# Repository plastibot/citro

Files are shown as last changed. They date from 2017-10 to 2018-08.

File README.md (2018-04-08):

# citro

A 3D Printed Biped Robot based on MiniPlan6 integrating a Pi Zero W, Pi Camera, Speakers, Microphone and Accelerometer.

## Firmware Installation Instructions

### Install Arduino
Install Arduino IDE 1.6.8 level which can be found on previous relelases at the Arduino website [here](https://www.arduino.cc/en/Main/OldSoftwareReleases#1.5.x)

### install ESP8266 suite
Starting with 1.6.4, Arduino allows installation of third-party platform packages using Boards Manager. 

- Start Arduino and open Preferences window.
- Enter http://arduino.esp8266.com/stable/package_esp8266com_index.json into Additional Board Manager URLs field. You can add * - multiple URLs, separating them with commas.
- Open Boards Manager from Tools > Board menu and install esp8266 platform.
- Select your ESP8266 board from Tools > Board menu after installation.

### Download tool for SPIFFS support

- Download the tool: https://github.com/esp8266/arduino-esp8266fs-plugin/releases/download/0.3.0/ESP8266FS-0.3.0.zip.
- In your Arduino sketchbook directory, create tools directory if it doesn’t exist yet
- Unpack the tool into tools directory (the path will look like <home_dir>/Arduino/tools/ESP8266FS/tool/esp8266fs.jar)
- Restart Arduino IDE

``` bash
$ cd ~/Arduino
$ makedir tools
$ cd tools
$ wget https://github.com/esp8266/arduino-esp8266fs-plugin/releases/download/0.3.0/ESP8266FS-0.3.0.zip
$ unzip ESP8266FS-0.3.0.zip
```

### Downloading required Libraries
Download the following libraries from adafruit into your Arduino/libraries folder

``` bash
$ cd ~/Arduino/libraries
$ git clone https://github.com/adafruit/Adafruit_SSD1306.git
$ git clone https://github.com/adafruit/Adafruit-GFX-Library.git
$ git clone https://github.com/adafruit/Adafruit-PWM-Servo-Driver-Library.git

```

### Clone Repository for Citro

```
$ cd ~
$ git clone https://github.com/plastibot/citro.git
```

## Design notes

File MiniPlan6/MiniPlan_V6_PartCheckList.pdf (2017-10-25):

Part No. | Print Settings | Qty.

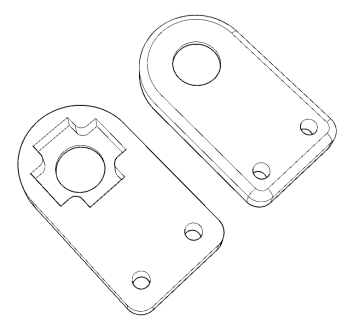
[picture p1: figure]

MiniPlan6_11 | Supports: No Resolution: 0.2mm Infill: 30% | □ 4

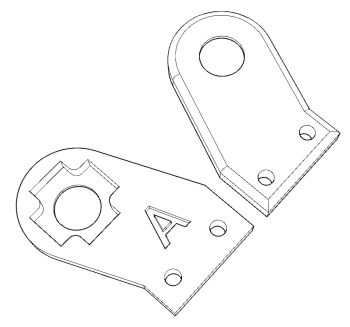
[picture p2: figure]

MiniPlan6_12A | Supports: No Resolution: 0.2mm Infill: 30% | □ 3

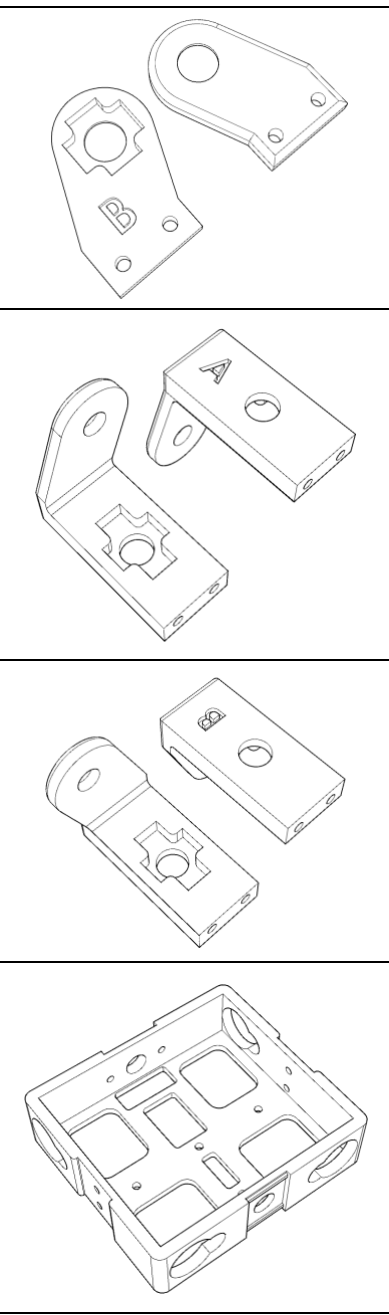
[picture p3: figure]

MiniPlan6_12B | Supports: No Resolution: 0.2mm Infill: 30% | □ 3
MiniPlan6_13A | Supports: No Resolution: 0.2mm Infill: 30% | □ 2
MiniPlan6_13B | Supports: No Resolution: 0.2mm Infill: 30% | □ 2
MiniPlan6_20 | Supports: No Resolution: 0.2mm Infill: 30% | □ 1

Part No. | Print Settings | Qty.

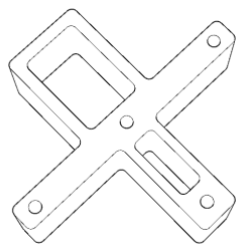
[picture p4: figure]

MiniPlan6_21 | Supports: No Resolution: 0.2mm Infill: 30% | □ 1
MiniPlan6_22B | Supports: No Resolution: 0.2mm Infill: 30% | □ 1

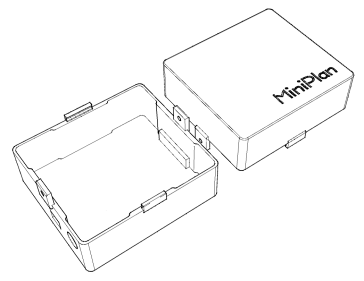
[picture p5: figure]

MiniPlan6_23B | Supports: No Resolution: 0.2mm Infill: 30% | □ 1

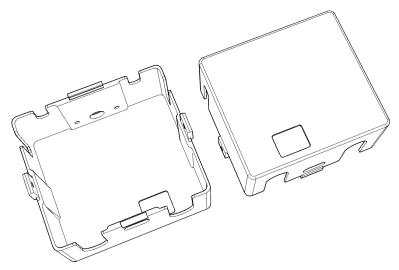
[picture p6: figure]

MiniPlan6_24B | Supports: No Resolution: 0.2mm Infill: 30% | □ 1

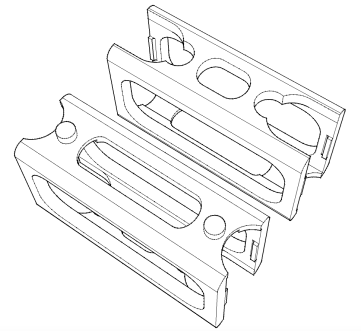
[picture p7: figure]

MiniPlan6_30 | Brim: Yes Supports: No Resolution: 0.2mm Infill: 30% | □ 2
MiniPlan6_31L | Supports: No Resolution: 0.2mm Infill: 20% | □ 1

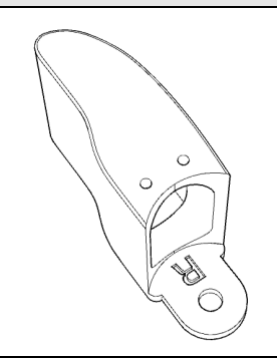
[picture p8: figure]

Part No. | Print Settings | Qty.
MiniPlan6_31R | Supports: No Resolution: 0.2mm Infill: 20% | □ 1

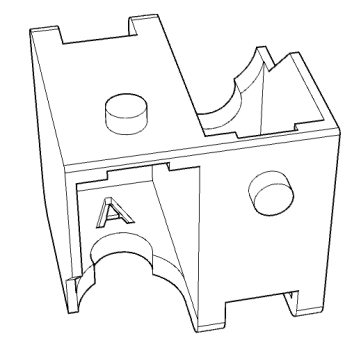
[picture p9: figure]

MiniPlan6_40A | Supports: Yes Resolution: 0.2mm Infill: 30% | □ 1

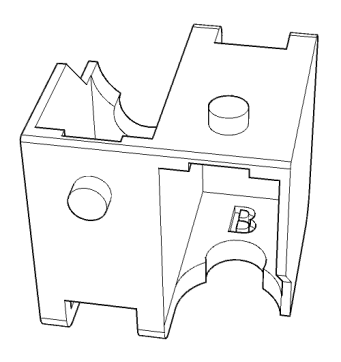
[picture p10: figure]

MiniPlan6_40B | Supports: Yes Resolution: 0.2mm Infill: 30% | □ 1

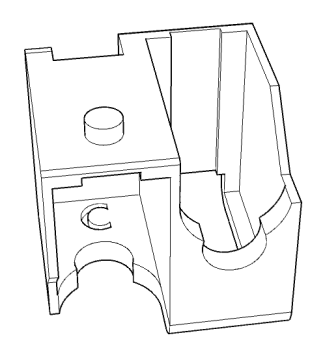
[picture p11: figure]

MiniPlan6_40C | Supports: Yes Resolution: 0.2mm Infill: 30% | □ 1
MiniPlan6_40D | Supports: Yes Resolution: 0.2mm Infill: 30% | □ 1

Part No. | Print Settings | Qty.

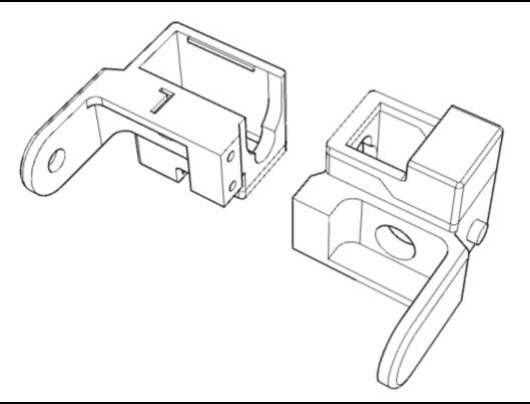
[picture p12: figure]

MiniPlan6_41L | Supports: No Resolution: 0.2mm Infill: 30% | □ 1

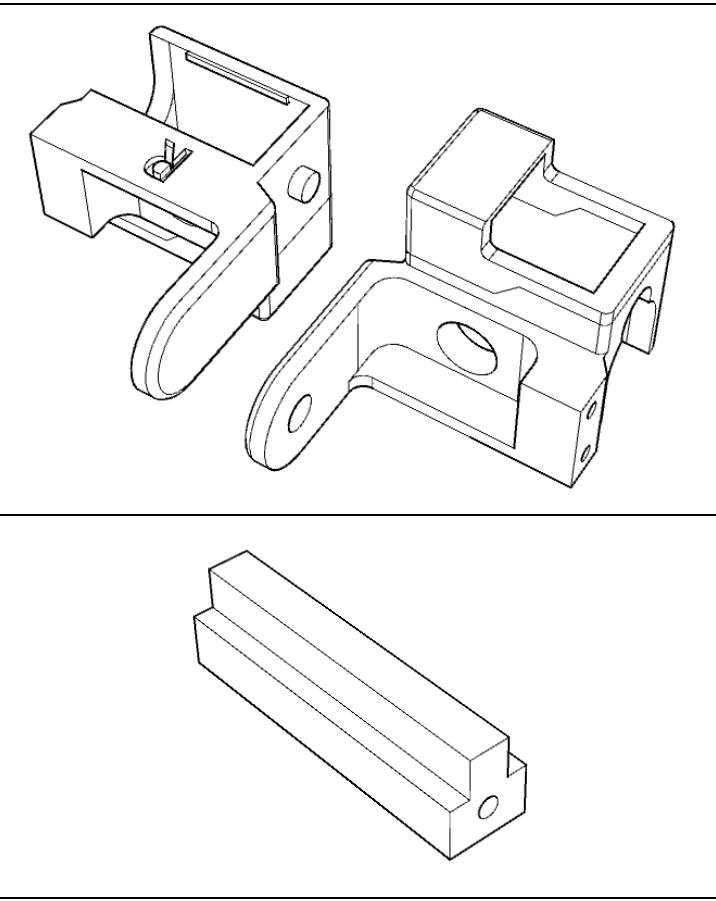
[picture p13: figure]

MiniPlan6_41R | Supports: No Resolution: 0.2mm Infill: 30% | □ 1
MiniPlan6_42 | Supports: No Resolution: 0.2mm Infill: 30% | □ 2

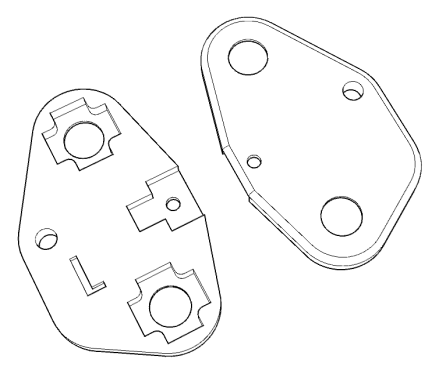
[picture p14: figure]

MiniPlan6_43L | Supports: No Resolution: 0.2mm Infill: 30% | □ 1

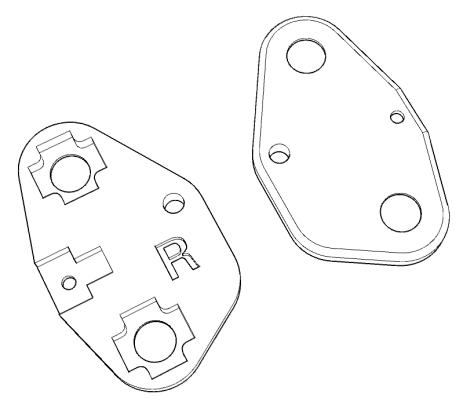
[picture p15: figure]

MiniPlan6_43R | Supports: No Resolution: 0.2mm Infill: 30% | □ 1

Part No. | Print Settings | Qty.

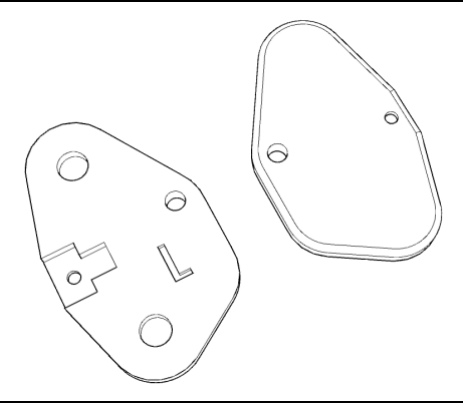
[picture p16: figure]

MiniPlan6_44L | Supports: No Resolution: 0.2mm Infill: 30% | □ 1
MiniPlan6_44R | Supports: No Resolution: 0.2mm Infill: 30% | □ 1
MiniPlan6_45L | Supports: No Resolution: 0.2mm Infill: 30% | □ 1
MiniPlan6_45R | Supports: No Resolution: 0.2mm Infill: 30% | □ 1

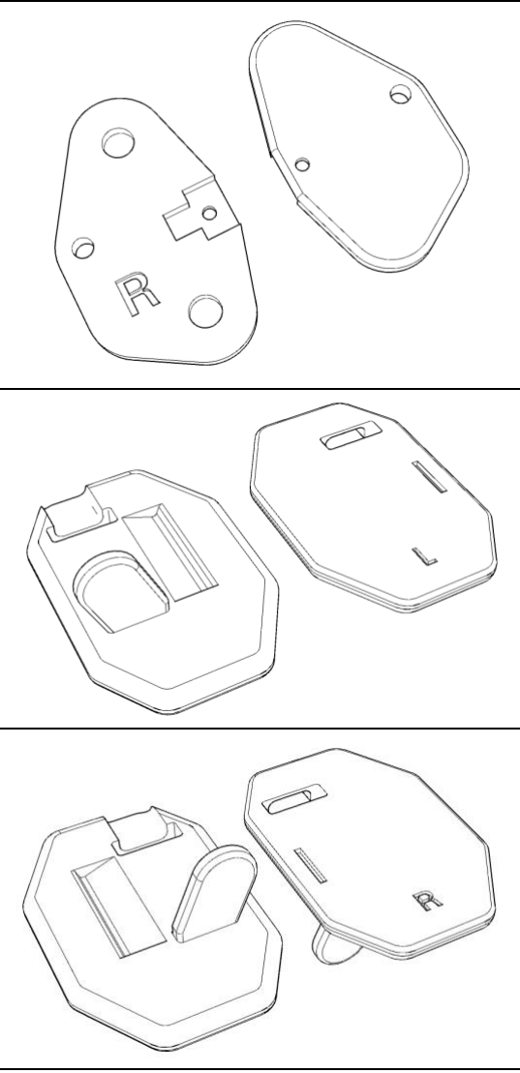
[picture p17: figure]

Print Check & Servo Cut Tool | Part No. | Print Settings | Qty.

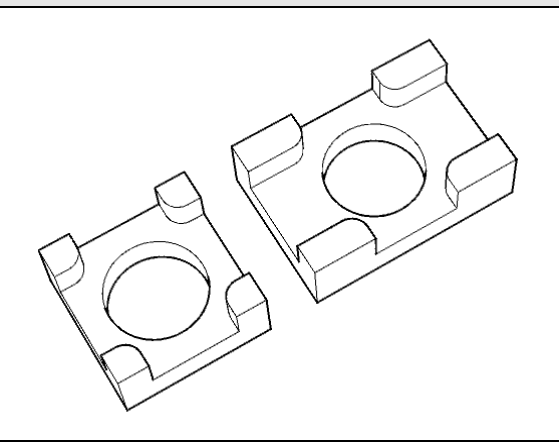
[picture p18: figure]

| MiniPlan6_70 | Supports: No Resolution: 0.2mm Infill: 100% | □ 1

Neck Mode 1 (Fix) | Part No. | Print Settings | Qty.
| MiniPlan6_50 | Supports: No Resolution: 0.2mm Infill: 100% | □ 1
Neck Mode 2 (Can Move) | Part No. | Print Settings | Qty.

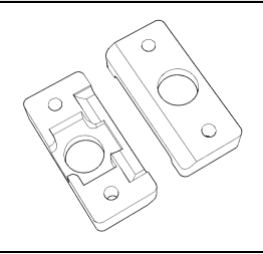
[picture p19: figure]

| MiniPlan6_51 | Supports: No Resolution: 0.2mm Infill: 100% | □ 1
| MiniPlan5_43 | Supports: No Resolution: 0.2mm Infill: 30% | □ 1

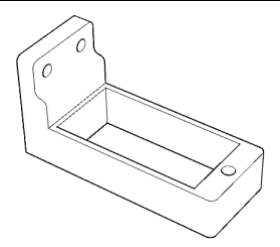
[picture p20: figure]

Skateboard | Part No. | Print Settings | Qty.

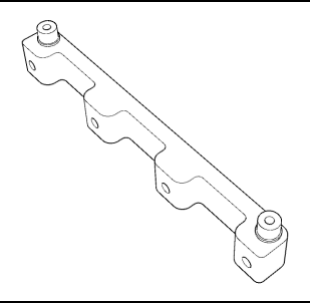
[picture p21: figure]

| MiniPlan6_60 | Supports: No Resolution: 0.2mm Infill: 30% | □ 4

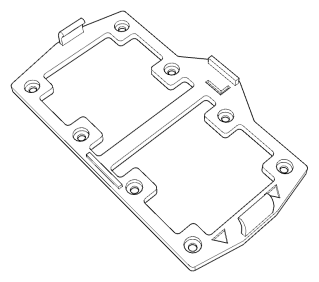
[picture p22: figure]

| MiniPlan6_61L | Supports: No Resolution: 0.2mm Infill: 100% | □ 1
| MiniPlan6_61R | Supports: No Resolution: 0.2mm Infill: 100% | □ 1

Head | Part No. | Print Settings | Qty.

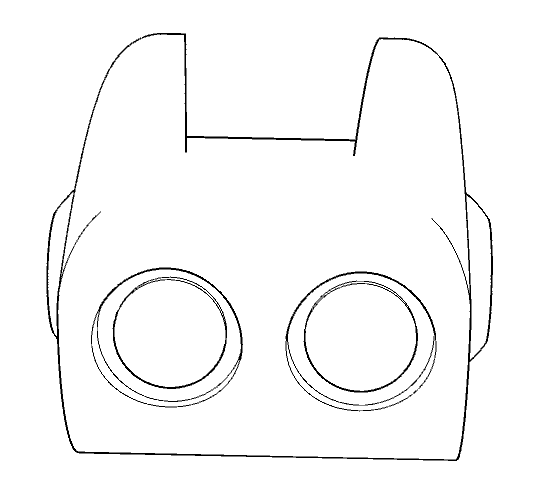
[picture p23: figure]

| MiniPlan5_40 Or MiniPlan5_40_chang | Rafts: Yes Supports: Yes Resolution: 0.2mm Infill: 20% | □ 1

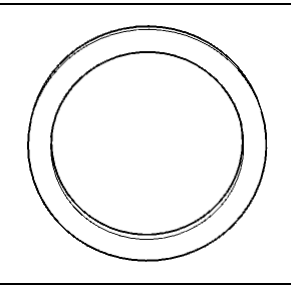
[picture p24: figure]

| MiniPlan51_70 | Supports: No Resolution: 0.2mm Infill: 100% | □ 2

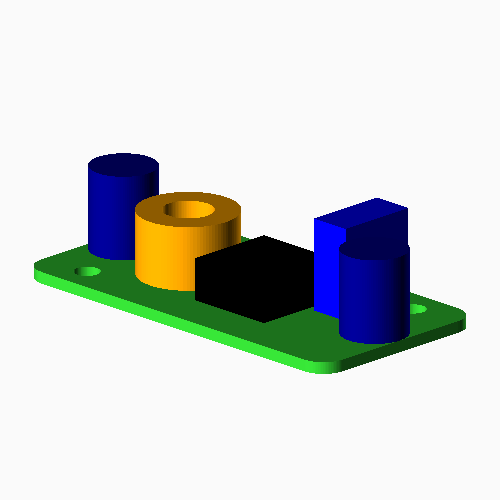
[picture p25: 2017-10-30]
images/electronics_dc_dc.png

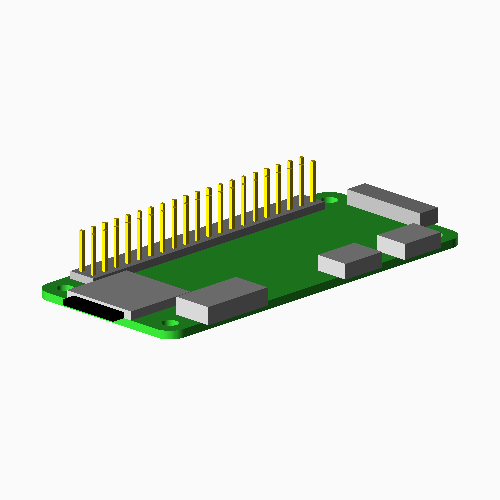
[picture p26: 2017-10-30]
images/electronics_PiZero.png

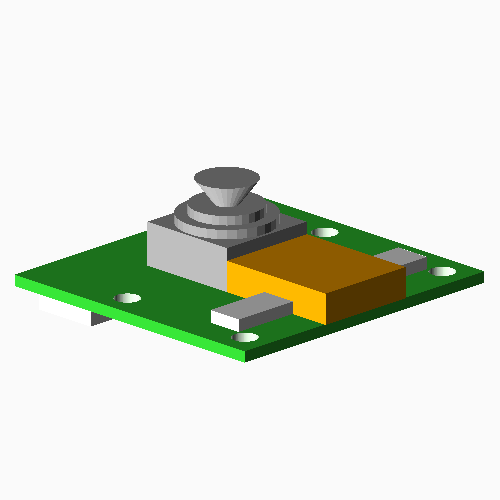
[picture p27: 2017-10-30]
images/electronics_PiCamera.png

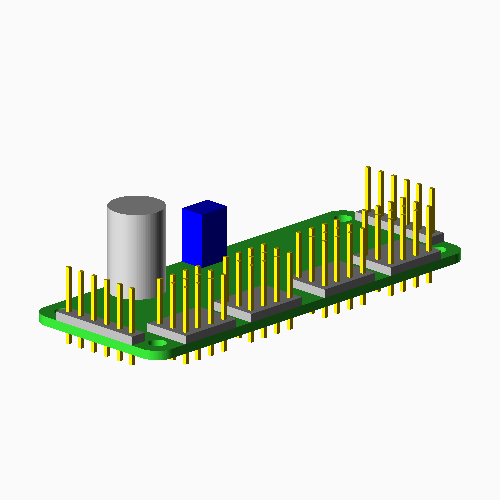
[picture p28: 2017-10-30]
images/electronics_pca9685.png

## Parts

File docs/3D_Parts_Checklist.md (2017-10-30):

###3D PRINTED PARTS CHECKLIST

**image** | **Part Number** | **Quantity** | **Print Settings**
--------- | --------------- | ------------ | ------------------
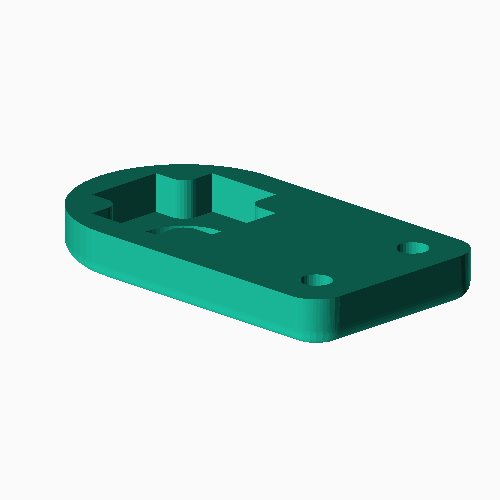
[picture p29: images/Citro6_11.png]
 | Citro6\_11 | 4 |  **Layers:** 0.2mm <br>  **Infill:** 30% <br>  **Supports:** No <br>  **Cooling:** Enabled
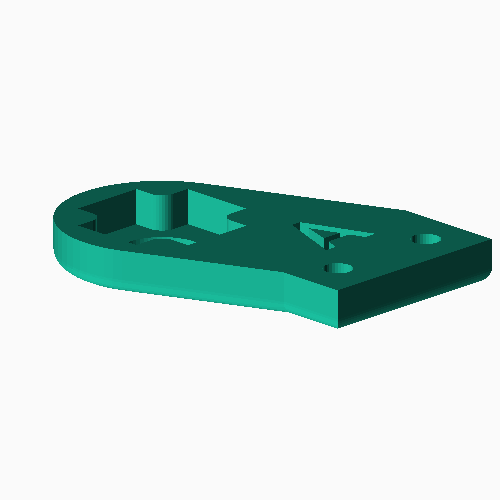
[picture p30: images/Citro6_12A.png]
 | Citro6\_12A | 3 |  **Layers:** 0.2mm <br>  **Infill:** 30% <br>  **Supports:** No <br>  **Cooling:** Enabled
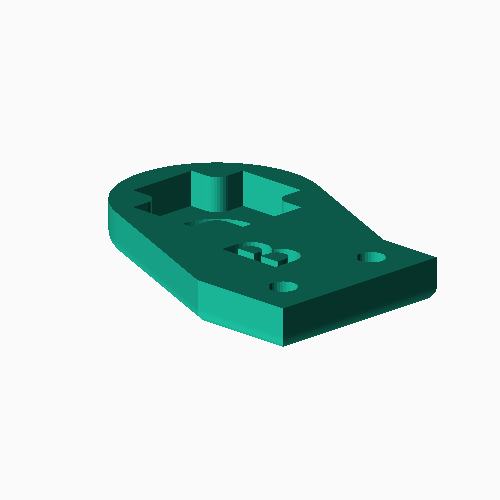
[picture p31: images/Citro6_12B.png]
 | Citro6\_12B | 3 |  **Layers:** 0.2mm <br>  **Infill:** 30% <br>  **Supports:** No <br>  **Cooling:** Enabled
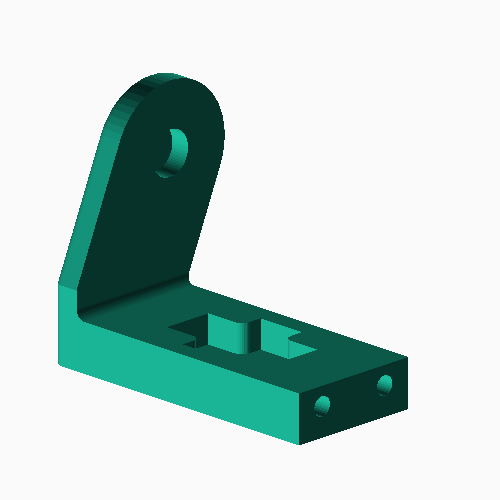
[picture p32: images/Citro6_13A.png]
 | Citro6\_13A | 2 |  **Layers:** 0.2mm <br>  **Infill:** 30% <br>  **Supports:** No <br>  **Cooling:** Enabled
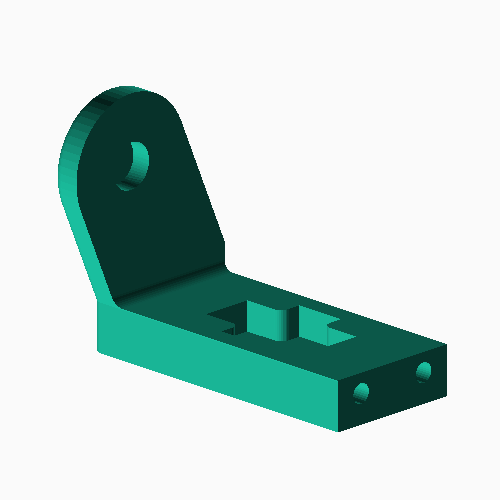
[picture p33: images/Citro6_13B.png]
 | Citro6\_13B | 2 |  **Layers:** 0.2mm <br>  **Infill:** 30% <br>  **Supports:** No <br>  **Cooling:** Enabled
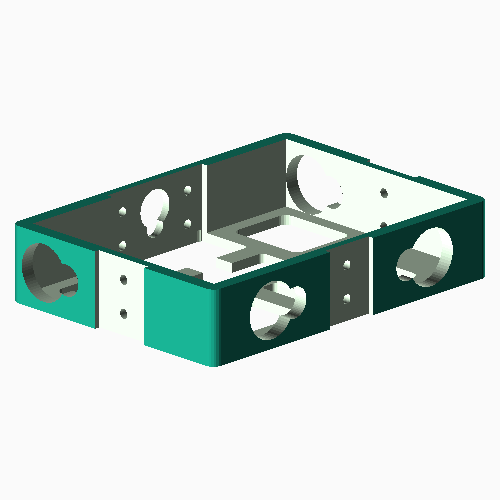
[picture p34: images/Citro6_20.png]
 | Citro6\_20 | 1 |  **Layers:** 0.2mm <br>  **Infill:** 30% <br>  **Supports:** No <br>  **Cooling:** Enabled
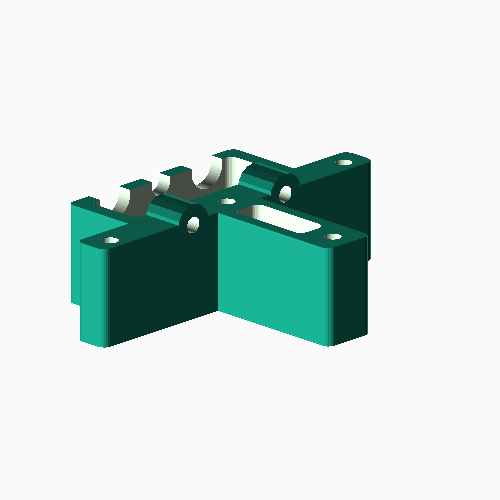
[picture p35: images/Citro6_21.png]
 | Citro6\_21 | 1 |  **Layers:** 0.2mm <br>  **Infill:** 30% <br>  **Supports:** No <br>  **Cooling:** Enabled
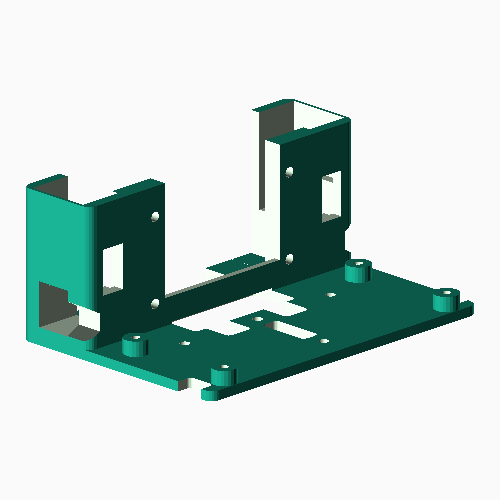
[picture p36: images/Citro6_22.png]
 | Citro6\_22 | 1 |  **Layers:** 0.2mm <br>  **Infill:** 30% <br>  **Supports:** No <br>  **Cooling:** Enabled
 | Citro6\_23 | 1 |  **Layers:** 0.2mm <br>  **Infill:** 30% <br>  **Supports:** No <br>  **Cooling:** Disabled
 | Citro6\_25 | 1 |  **Layers:** 0.2mm <br>  **Infill:** 30% <br>  **Supports:** No <br>  **Cooling:** Enabled <br>  **Brim:** Yes
 | Citro6\_26 | 1 |  **Layers:** 0.2mm <br>  **Infill:** 30% <br>  **Supports:** No <br>  **Cooling:** Enabled
 | Citro6\_27 | 4 |  **Layers:** 0.2mm <br>  **Infill:** 30% <br>  **Supports:** No <br>  **Cooling:** Enabled
 | Citro6\_30 | 2 |  **Layers:** 0.2mm <br>  **Infill:** 30% <br>  **Supports:** No <br>  **Cooling:** Enabled
 | Citro6\_31L | 1 |  **Layers:** 0.2mm <br>  **Infill:** 30% <br>  **Supports:** No <br>  **Cooling:** Enabled
 | Citro6\_31R | 1 |  **Layers:** 0.2mm <br>  **Infill:** 30% <br>  **Supports:** No <br>  **Cooling:** Enabled
 | Citro6\_40A | 1 |  **Layers:** 0.2mm <br>  **Infill:** 30% <br>  **Supports:** No <br>  **Cooling:** Enabled
 | Citro6\_40B | 1 |  **Layers:** 0.2mm <br>  **Infill:** 30% <br>  **Supports:** No <br>  **Cooling:** Enabled
 | Citro6\_40C | 1 |  **Layers:** 0.2mm <br>  **Infill:** 30% <br>  **Supports:** No <br>  **Cooling:** Enabled
 | Citro6\_40D | 1 |  **Layers:** 0.2mm <br>  **Infill:** 30% <br>  **Supports:** No <br>  **Cooling:** Enabled
 | Citro6\_41L | 1 |  **Layers:** 0.2mm <br>  **Infill:** 30% <br>  **Supports:** No <br>  **Cooling:** Enabled
 | Citro6\_41R | 1 |  **Layers:** 0.2mm <br>  **Infill:** 30% <br>  **Supports:** No <br>  **Cooling:** Enabled
 | Citro6\_42 | 2 |  **Layers:** 0.2mm <br>  **Infill:** 30% <br>  **Supports:** No <br>  **Cooling:** Enabled
 | Citro6\_43L | 1 |  **Layers:** 0.2mm <br>  **Infill:** 30% <br>  **Supports:** No <br>  **Cooling:** Enabled
 | Citro6\_43R | 1 |  **Layers:** 0.2mm <br>  **Infill:** 30% <br>  **Supports:** No <br>  **Cooling:** Enabled
 | Citro6\_44L | 1 |  **Layers:** 0.2mm <br>  **Infill:** 30% <br>  **Supports:** No <br>  **Cooling:** Enabled
 | Citro6\_44R | 1 |  **Layers:** 0.2mm <br>  **Infill:** 30% <br>  **Supports:** No <br>  **Cooling:** Enabled
 | Citro6\_45L | 1 |  **Layers:** 0.2mm <br>  **Infill:** 30% <br>  **Supports:** No <br>  **Cooling:** Enabled
 | Citro6\_45R | 1 |  **Layers:** 0.2mm <br>  **Infill:** 30% <br>  **Supports:** No <br>  **Cooling:** Enabled
 | Citro6\_50 | 1 |  **Layers:** 0.2mm <br>  **Infill:** 30% <br>  **Supports:** No <br>  **Cooling:** Enabled 
 | Citro6\_51 | 1 |  **Layers:** 0.2mm <br>  **Infill:** 30% <br>  **Supports:** No <br>  **Cooling:** Enabled
 | Citro6\_52 | 1 |  **Layers:** 0.2mm <br>  **Infill:** 30% <br>  **Supports:** No <br>  **Cooling:** Enabled
 | Citro6\_53 | 1 |  **Layers:** 0.2mm <br>  **Infill:** 30% <br>  **Supports:** No <br>  **Cooling:** Enabled
 | Citro6\_60 | 1 |  **Layers:** 0.2mm <br>  **Infill:** 30% <br>  **Supports:** No <br>  **Cooling:** Enabled
 | Citro6\_61L | 1 |  **Layers:** 0.2mm <br>  **Infill:** 30% <br>  **Supports:** No <br>  **Cooling:** Enabled
 | Citro6\_61R | 1 |  **Layers:** 0.2mm <br>  **Infill:** 30% <br>  **Supports:** No <br>  **Cooling:** Enabled
 | Citro6\_70 | 1 |  **Layers:** 0.2mm <br>  **Infill:** 30% <br>  **Supports:** No <br>  **Cooling:** Enabled
-----

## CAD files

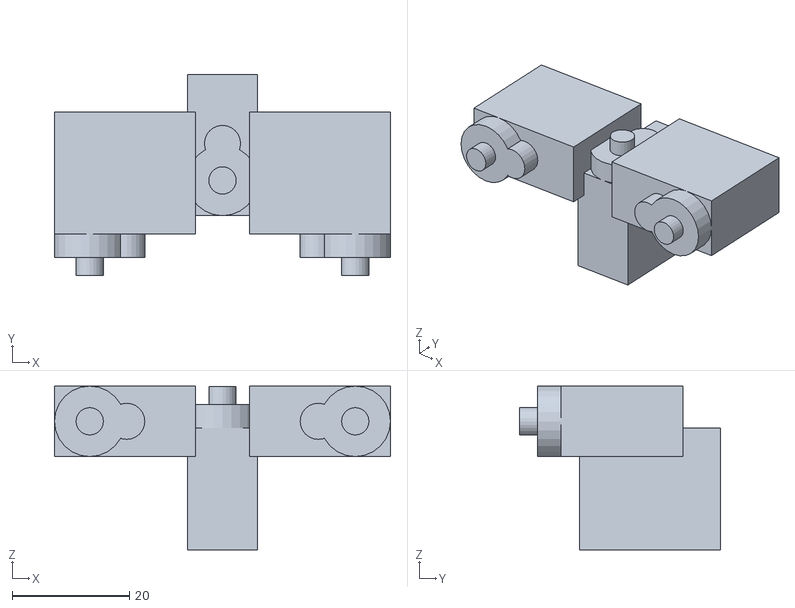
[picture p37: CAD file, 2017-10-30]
stl/Assembly_Steps.stl
57.2 x 34.1 x 27.9

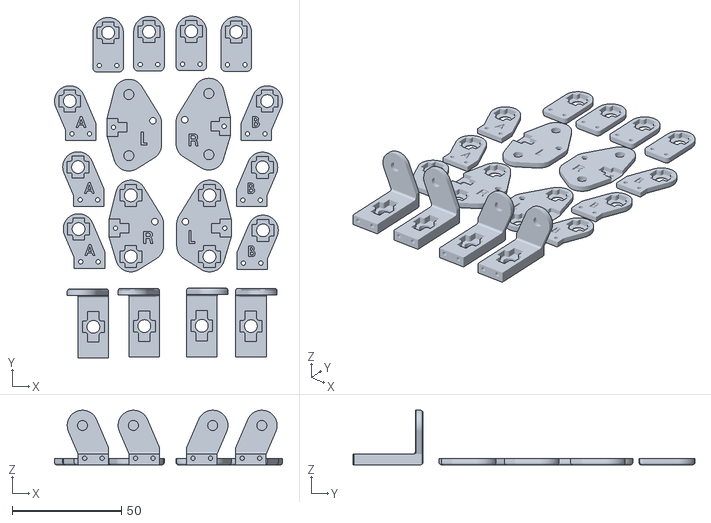
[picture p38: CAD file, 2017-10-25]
MiniPlan6/bundles/MiniPlan6_11&12&13&43&44___Pmdl-N35-7R03_F30-Cd_ABSPLA-L20P3B4r-I15r-Sd_2215.stl
104.3 x 156.5 x 25.0

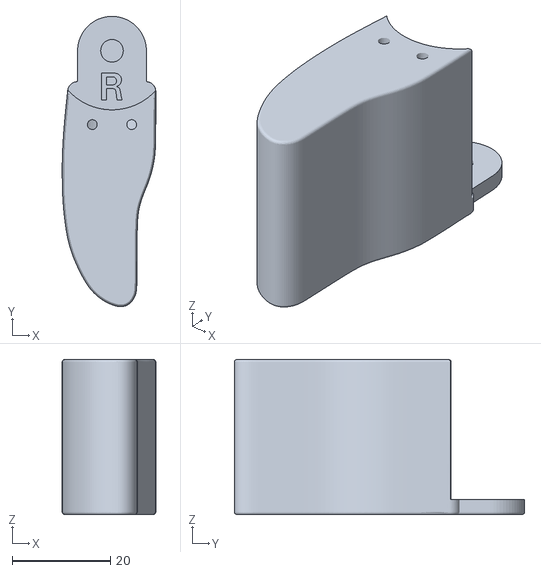
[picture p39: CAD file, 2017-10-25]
MiniPlan6/MiniPlan6_31R.stl
19.0 x 59.0 x 31.5

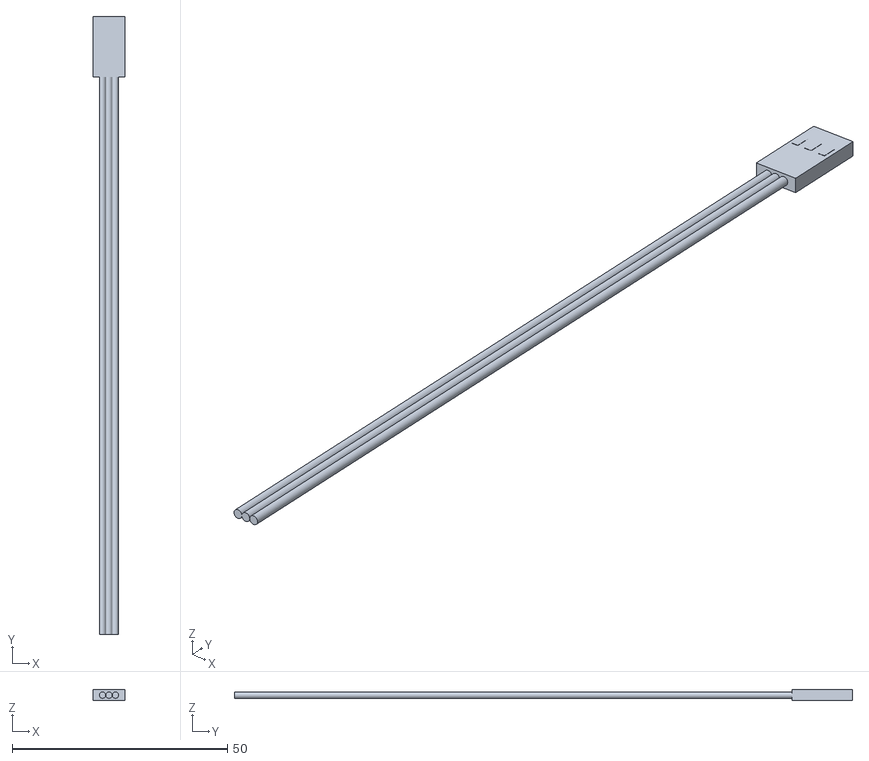
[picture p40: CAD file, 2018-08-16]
stl/Servo_wire.stl
7.50 x 143.4 x 2.55

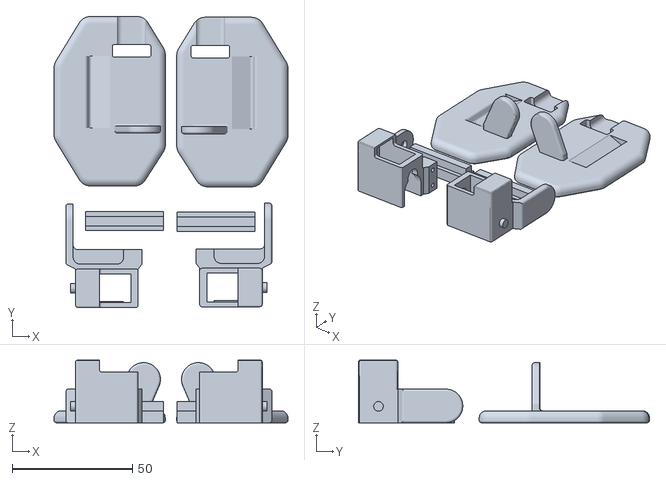
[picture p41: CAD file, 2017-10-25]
MiniPlan6/bundles/MiniPlan6_41&45&42___Pmdl-N35-7R03_F30-Cd_ABSPLA-L20P3B4r-I15r-Sd_2251.stl
97.1 x 120.8 x 26.0

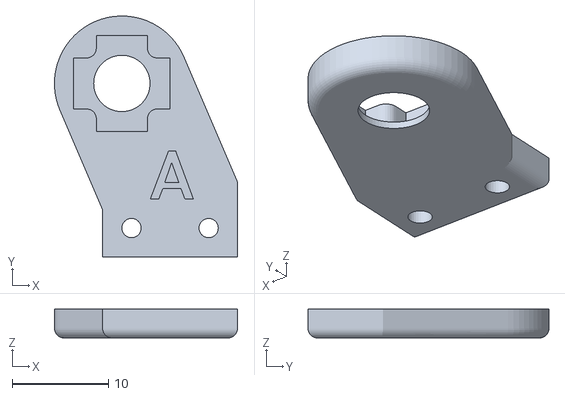
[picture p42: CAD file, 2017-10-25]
MiniPlan6/MiniPlan6_12A.stl
19.0 x 25.0 x 3.00

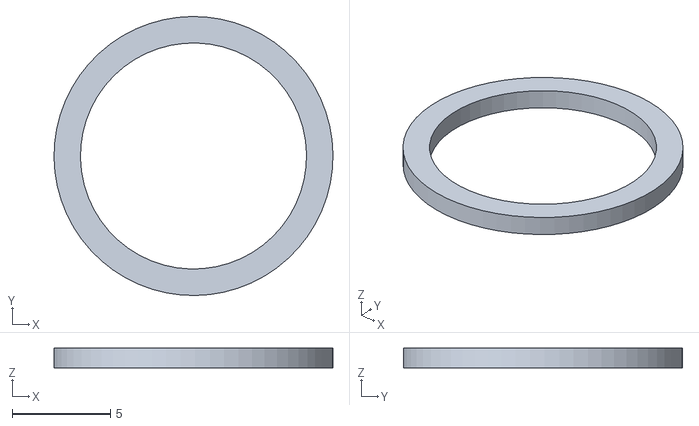
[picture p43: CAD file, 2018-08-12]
stl/Citro6_54.stl
14.2 x 14.2 x 1.00

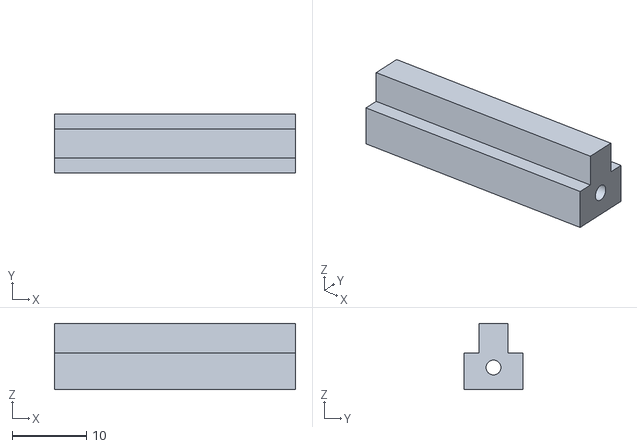
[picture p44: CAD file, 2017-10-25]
MiniPlan6/MiniPlan6_42.stl
32.5 x 7.94 x 8.93

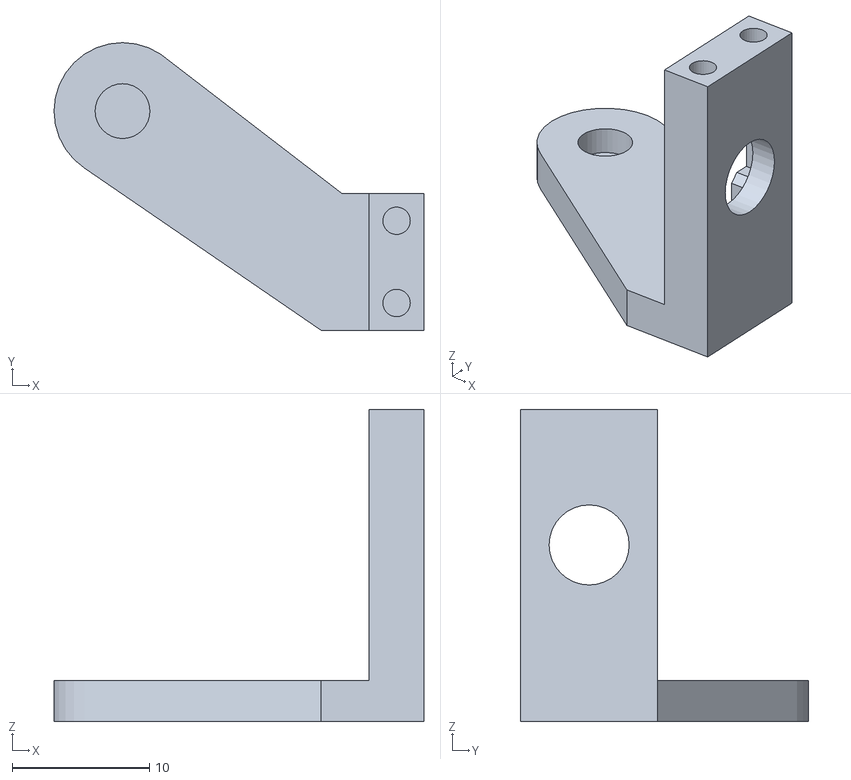
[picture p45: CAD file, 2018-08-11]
stl/Citro6_52a.stl
27.0 x 21.0 x 22.8

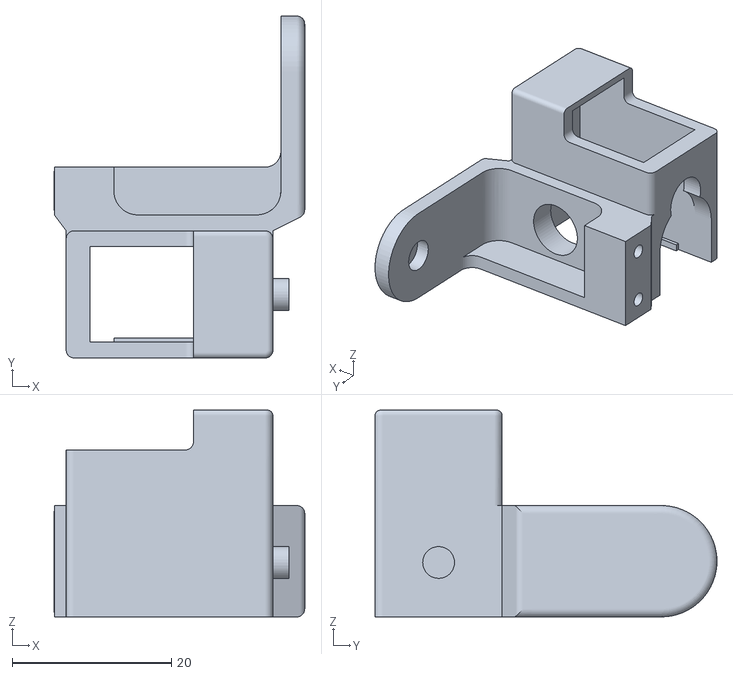
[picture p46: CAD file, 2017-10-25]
MiniPlan6/MiniPlan6_41R.stl
31.5 x 43.0 x 26.0

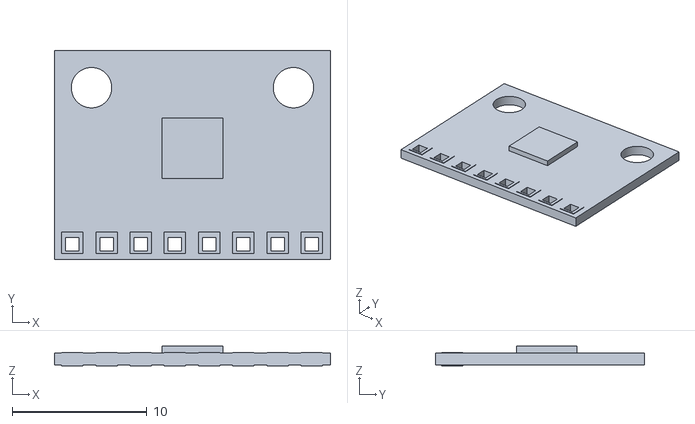
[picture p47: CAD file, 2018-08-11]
stl/electronics_imu.stl
20.5 x 15.5 x 1.45

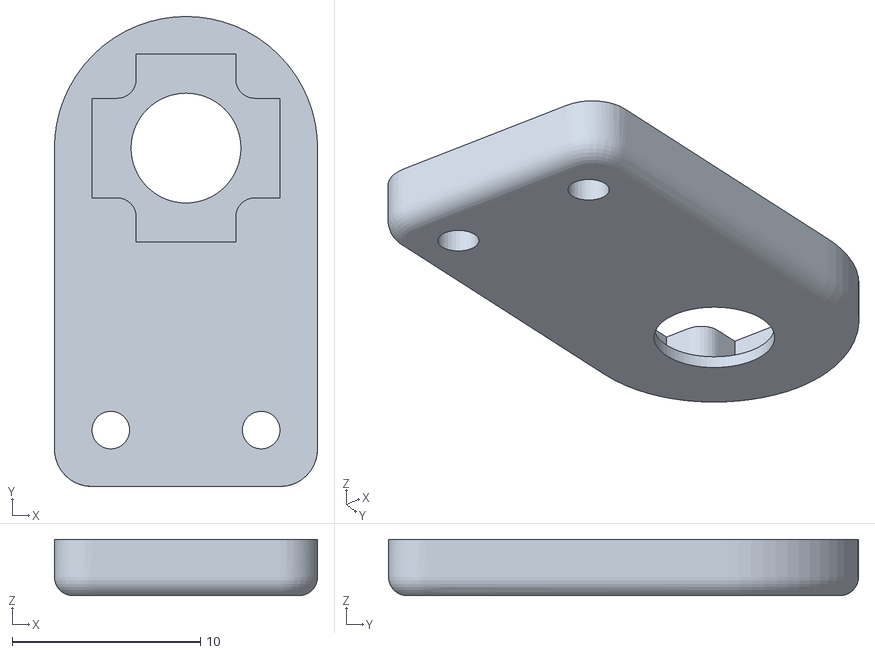
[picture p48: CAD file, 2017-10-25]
MiniPlan6/MiniPlan6_11.stl
14.0 x 25.0 x 3.00

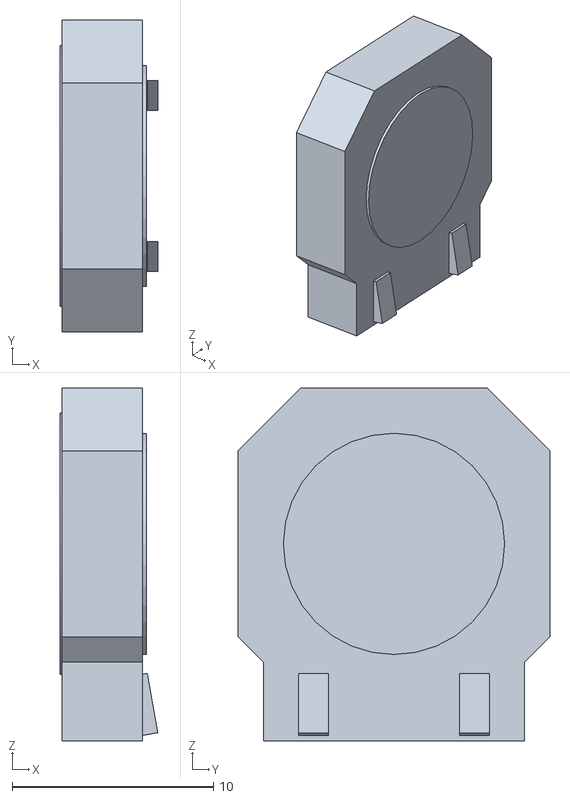
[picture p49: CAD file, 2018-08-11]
stl/electronics_speaker.stl
4.85 x 15.5 x 17.6

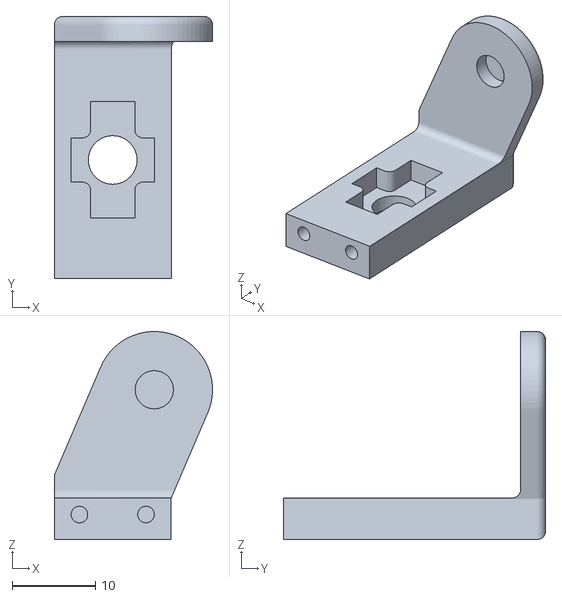
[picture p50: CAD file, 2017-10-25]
MiniPlan6/MiniPlan6_13A.stl
19.0 x 31.5 x 25.0

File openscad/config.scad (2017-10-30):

//Parameters for 12g servo
$fn = 24;
//x,y,z => l,w,h

tap_r = 0.85;
hole_r = 1.0;

servo_l         = 12;  // was 12
servo_w         = 24;  // was 23
body_h          = 20.80;

servo_h         = 27; //not used in code was 27

wing_w          = 4.5;
wing_h          = 2.33;
wing_place      = 16.3;   
hole_offset     = 2.2;    //not checked
mount_hole_r    = 2/2;
mount_slot      = 1;

servo_ww        = servo_w+wing_w*2; // not used in code but is handy number

hub_h           = 4;
small_hub_r     = 6.15/2;  
horn_r          = 4.66/2;
horn_h          = 3;

wire_l          = 4;
wire_w          = 1.5;
wire_h          = 1;
wire_place      = 4.8;

servo_full_w    = servo_w+wing_w*2;

rad = 2;




//Parameters for 5g servo

servo5_l         = 8.6; 
servo5_w         = 18.6; 
body5_h          = 14.65;


hub5_h = 2.15;
small_hub5_r = 4.6/2;  
horn5_r = 4.66/2;
horn5_h = 3;

servo5_h         = body5_h+hub5_h+horn5_h;

mount_x = servo5_l + 2;
mount_y = servo5_w + 2;
mount_round = 1;
servo_tol = 0.2;
servo5_x     = servo5_l + servo_tol*2; //~12
servo5_y     = servo5_w + servo_tol*8; //~23

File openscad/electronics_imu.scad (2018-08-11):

$fn=100;


imu();

module imu(){
    
        difference(){
        union(){
            color("limegreen")
            translate([-20.5/2, -15.5/2, 0])
            cube([20.5, 15.5, 0.9]);
            
            
            //mpu6050
            color("black")
            translate([-4.5/2, -3.5/2, 0.9])
            cube([4.5, 4.5, 0.5]);
            

            
            
            //led
            //color("white")
            //translate([-20/2, -8.5/2+2.4-7, 0.9])
            //cube([20, 3, 1]);            
            
            
            //connector
            //color("white")
            //translate([-20.8/2, -5.5+24/2, -2.4])
            //cube([20.8, 5.5, 2.4]);
            
            translate([-4*2.54-0.5,-16.5/2,0.45])
            color("gold")
            for(x=[0:8-1],y=[0:1-1])
                translate([x*2.54+(1.27+.6)/2,y*2.54+(1.27+.6)/2,-0.5]) cube([1.6,1.6,1]);
            
            
    
        }
          
       
        translate([-15/2, 25/2-7.5,-1]) cylinder(d=3, h=3);
        translate([15/2, 25/2-7.5,-1]) cylinder(d=3, h=3);
        
        translate([-4*2.54-0.5,-15.5/2,0.45])
        for(x=[0:8-1],y=[0:1-1])
                translate([x*2.54+(1.27+1.2)/2,y*2.54+(1.27)/2,-0.75]) cube([1,1,1.5]);
        

    }
    
}

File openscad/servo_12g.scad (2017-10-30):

include <config.scad>


servo_12g();


$fn = 24;
//x,y,z => l,w,h


module servo_12g() {
  
    translate([-servo_l/2, -servo_w/2, -body_h/2-hub_h/2-horn_h/2]) {
    
        color("white") 
        translate([servo_l/2,servo_l/2,body_h+hub_h])
        cylinder(r=horn_r,h=horn_h);
        
        color("deepSkyBlue",.7) //deepSkyBlue
        union() {
            cube([servo_l,servo_w,body_h]);
            translate([servo_l/2,servo_l/2,body_h])
            cylinder(r=servo_l/2,h=hub_h);
            translate([servo_l/2,servo_l/2+6.30,body_h])
            cylinder(r=small_hub_r,h=hub_h);
            
        }
    }
}

module roundedRect(size, radius)
{
x = size[0];
y = size[1];
z = size[2];

translate([x/2+radius/2, y/2+radius/2, 0]){
linear_extrude(height=z)
hull()
{
// place 4 circles in the corners, with the given radius
translate([(-x/2)+(radius/2), (-y/2)+(radius/2), 0])
circle(r=radius);

translate([(x/2)-(radius/2), (-y/2)+(radius/2), 0])
circle(r=radius);

translate([(-x/2)+(radius/2), (y/2)-(radius/2), 0])
circle(r=radius);

translate([(x/2)-(radius/2), (y/2)-(radius/2), 0])
circle(r=radius);
}
}
}

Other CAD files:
stl/wemos_d1_mini_pro_board.stl
MiniPlan6/MiniPlan6_61R.stl
stl/electronics_pca9685.stl
MiniPlan6/MiniPlan6_60.stl
openscad/servo_5g.scad
Citro6_RightLeg-new.blend
LefArrmAssemblyAnimation.blend
MiniPlan6/MiniPlan51_70.stl
MiniPlan6/MiniPlan5_40.stl
MiniPlan6/MiniPlan6_12B.stl
MiniPlan6/MiniPlan6_13B.stl
MiniPlan6/MiniPlan6_30.stl
MiniPlan6/MiniPlan6_31L.stl
MiniPlan6/MiniPlan6_40A.stl
MiniPlan6/MiniPlan6_40B.stl
MiniPlan6/MiniPlan6_40C.stl
MiniPlan6/MiniPlan6_40D.stl
MiniPlan6/MiniPlan6_41L.stl
MiniPlan6/MiniPlan6_43L.stl
MiniPlan6/MiniPlan6_43R.stl
MiniPlan6/MiniPlan6_44L.stl
MiniPlan6/MiniPlan6_44R.stl
MiniPlan6/MiniPlan6_45L.stl
MiniPlan6/MiniPlan6_45R.stl
MiniPlan6/MiniPlan6_61L.stl
MiniPlan6/MiniPlan6_70.stl
RightLegAssemblyAnimation.blend
openscad/Assembly_Steps.scad
openscad/Citro.scad
openscad/Citro6_11.scad
openscad/Citro6_12A.scad
openscad/Citro6_12B.scad
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

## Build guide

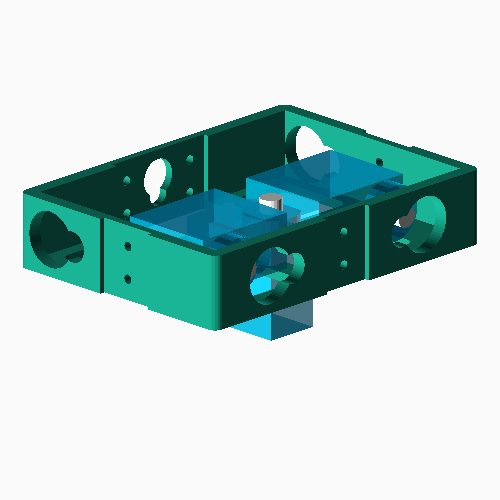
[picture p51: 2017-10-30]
images/Assembly_Steps.png

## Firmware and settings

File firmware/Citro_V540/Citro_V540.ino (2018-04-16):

// Last Edit: 2017-3-23
// First Edition

// Last Edit: 2017-5-14
// Correction EEPROM.commit(); vs. EEPROM.h conflict

// Last Edit: 2017-6-05
// Increase handleGetEEPROM transmmission EEPROM mode


//#include <SPI.h>
#include <Wire.h>
#include <Servo.h>
#include <ESP8266WiFi.h>
#include <ESP8266WebServer.h>
#include <FS.h>   // include the SPIFFS library
#include <Adafruit_PWMServoDriver.h>
#include <EEPROM.h>
#include <Adafruit_GFX.h>
#include <Adafruit_SSD1306.h>

// Version
String FW_Version = "Citro Firmware Version 5.40 (2018/04/10)";
String Thanks_1 = "Based on Miniplan V6 by Roy Chen and Mason Chen";
String Thanks_2 = "";
String ShowVoltage = "???V";

//  I2C Address 0x3C
#define OLED_RESET LED_BUILTIN
Adafruit_SSD1306 display(-1);

// I2C Address 0x40
Adafruit_PWMServoDriver pwm = Adafruit_PWMServoDriver();

// I2C Address 0x68
int gyro_address = 0x68;
int acc_calibration_value = 1000;
int gyro_pitch_data_raw, gyro_yaw_data_raw, accelerometer_data_raw;
int receive_counter;
long gyro_yaw_calibration_value, gyro_pitch_calibration_value;
unsigned long loop_timer;
float angle_gyro, angle_acc, angle;
byte start;

// Servos Matrix
const int ALLMATRIX = 21;    // 0 ~ 15 Servo + GPIO12 + GPIO13 + GPIO14 + GPIO16 + Run Time + Delay Time + PWM Frequency Calibration + Voltage Calibration
const int ALLSERVOS = 20;    // 0 ~ 15 Servo + GPIO12 + GPIO13 + GPIO14 + GPIO16

// ES08MDII Pulse Traveling 700us ~ 2300us (160 Degrees)
const int PWM_Frequency = 53;    // PWM frequency 50Hz
const int PWMRES_Min = 1;        // PWM Resolution 1
const int PWMRES_Max = 160;      // PWM Resolution 160
const int SERVOMIN = 145;        // 145
const int SERVOMAX = 472;        // 472

// Servo Delay Base Time
const int BASEDELAYTIME = 10;    // 10ms

// AP Password
const char WiFiAPPSK[] = "12345678";

// Voltage Detected
const int Input_Voltage = 795;       // 約 6.00V
const int Input_MinVoltage = 590;    // 約 5.90V 啟動低壓機制
int Voltage_Conter;
int Voltage_Cab = 0;
int Input_Voltage_Low = 0;
int Voltage = Input_Voltage;
int Set_Voltage = Input_Voltage;

// Servo PWM Frequency
int Set_PWM_Freq = PWM_Frequency;

// Motion Data Index
int Servo_PROGRAM;
int Servo_PROGRAM_Stack;
int Servo_cancel_motion = 0;

// Servo ID
int GPIO_ID;
int GPIO12_PWM;
int GPIO13_PWM;
int GPIO14_PWM;
int GPIO16_PWM;

// Backup Servo Value
int Running_Servo_POS [ALLMATRIX];

// Engineering model
int Engineering_Model;

// OLED Display Index
int OLED_Display_Index = 0;

// Start Web Server
ESP8266WebServer server(80);

// Start GPIO Software Servo
Servo GPIO12SERVO;
Servo GPIO13SERVO;
Servo GPIO14SERVO;
Servo GPIO16SERVO;

// Serial port input
byte byteRead;
long num1, num2,answer;
boolean mySwitch=false;


/*============================================================================*/
// ES08MDII - Davinci Posture
/////////////////////////////////////////////////////    0    ,    1    ,    2    ,    3    ,    4    ,    5    ,    6    ,    7    ,    8    ,    9    ,    10   ,    11   ,    12   ,    13   ,    14   ,    15   ,   G12   ,  G13   ,  G14   ,  G16   ,  ms
int Servo_Act_0 [ ] PROGMEM = {   60,      80,      50,     110,     50,     135,     50,      80,      80,     110,      25,      110,      50,      110,      80,      100,       90,       90,        90,        90,      0  };


/*============================================================================*/
// ES08MDII - Standby
/////////////////////////////////////////////////////    0    ,    1    ,    2    ,    3    ,    4    ,    5    ,    6    ,    7    ,    8    ,    9    ,    10   ,    11   ,    12   ,    13   ,    14   ,    15   ,   G12   ,  G13   ,  G14   ,  G16   ,  ms
int Servo_Act_1 [ ] PROGMEM = {   60,      80,      50,     110,     50,     135,    125,     80,      80,      35,       25,      110,      50,      110,      80,      100,       90,       90,        90,        90,      0  };


/*============================================================================*/
// Bow Action
int Servo_Prg_31_Step = 4;
int Servo_Prg_31 [][ALLMATRIX] PROGMEM = {
  //   0    ,    1    ,    2    ,    3    ,    4    ,    5    ,    6    ,    7    ,    8    ,    9    ,    10   ,    11   ,    12   ,    13   ,    14   ,    15   ,   G12   ,  G13   ,  G14   ,  G16   ,  ms
  {   60,      80,      50,     110,     50,     155,    115,     40,     140,     35,      105,     110,      50,      110,      80,      100,      90,        90,        90,       90,       500   },
  {   60,      65,      50,      60,      50,     155,    115,     40,     140,     35,      105,     110,      97,      110,      95,      100,      90,        90,        90,       90,       500   },
  {   60,      65,      50,      60,      50,     155,    115,     40,     140,     35,      105,     110,      97,      110,      95,      100,      90,        90,        90,       90,       1000 },
  {   60,      80,      50,     110,     50,     135,    125,     80,      80,      35,       25,      110,      50,      110,      80,      100,      90,        90,        90,       90,       800   }   // 立正
};


/*============================================================================*/
// Wave Action
int Servo_Prg_32_Step = 9;
int Servo_Prg_32 [][ALLMATRIX] PROGMEM = {
  //   0    ,    1    ,    2    ,    3    ,    4    ,    5    ,    6    ,    7    ,    8    ,    9    ,    10   ,    11   ,    12   ,    13   ,    14   ,    15   ,   G12   ,  G13   ,  G14   ,  G16   ,  ms
  {   60,      80,      50,     110,     50,     135,    125,     80,      60,      75,      125,     110,      50,      110,      80,      100,      90,        60,        90,        90,      500  },
  {   60,      80,      50,     110,     50,     135,    125,     80,      80,      35,      125,     110,      50,      110,      80,      100,      90,        60,        90,        90,      300  },
  {   60,      80,      50,     110,     50,     135,    125,     80,      60,      75,      125,     110,      50,      110,      80,      100,      90,        60,        90,        90,      300  },
  {   60,      80,      50,     110,     50,     135,    125,     80,      80,      35,      125,     110,      50,      110,      80,      100,      90,        60,        90,        90,      300  },

  {   60,      80,      50,     110,     50,      35,      85,     100,     80,      35,       30,      110,      50,      110,      80,      100,      90,       120,       90,        90,      500  },
  {   60,      80,      50,     110,     50,      35,     115,     80,      80,      35,       30,      110,      50,      110,      80,      100,      90,       120,       90,        90,      300  },
  {   60,      80,      50,     110,     50,      35,      85,     100,     80,      35,       30,      110,      50,      110,      80,      100,      90,       120,       90,        90,      300  },
  {   60,      80,      50,     110,     50,      35,     115,     80,      80,      35,       30,      110,      50,      110,      80,      100,      90,       120,       90,        90,      300  },

  {   60,      80,      50,     110,     50,     135,    125,     80,      80,      35,       25,      110,      50,      110,      80,      100,      90,        90,        90,        90,      800  }   // 立正
};


/*============================================================================*/
// Ironman Action
int Servo_Prg_33_Step = 8;
int Servo_Prg_33 [][ALLMATRIX] PROGMEM = {
  //   0    ,    1    ,    2    ,    3    ,    4    ,    5    ,    6    ,    7    ,    8    ,    9    ,    10   ,    11   ,    12   ,    13   ,    14   ,    15   ,   G12   ,  G13   ,  G14   ,  G16   ,  ms
  {   50,      80,      50,     110,     45,     155,    105,    120,     40,     105,      25,      100,      50,      110,      80,       90,       90,        60,        90,        90,      300  },
  {   50,      80,      50,     110,     45,     155,    105,    120,     40,     105,      25,      100,      50,      110,      80,       90,       90,        60,        90,        90,      800  },

  {   70,      80,      50,     110,     60,     135,     55,     120,     40,      55,        5,       115,      50,      110,      80,      110,      90,       120,       90,        90,      300  },
  {   70,      80,      50,     110,     60,     135,     55,     120,     40,      55,        5,       115,      50,      110,      80,      110,      90,       120,       90,        90,      800  },

  {   60,      80,      50,     110,     50,      55,     105,    120,     40,      55,      105,     110,      50,      110,      80,      100,      90,        90,        90,        90,      500  },
  {   60,      65,      50,      95,      50,      55,     140,    120,     40,      15,      105,     110,      65,      110,      94,      100,      90,        90,        90,        90,      500  },

  {   60,      65,      50,      95,      50,      55,     140,    120,     40,      15,      105,     110,      65,      110,      94,      100,      90,        90,        90,        90,      800  },
  {   60,      80,      50,     110,     50,     135,    125,     80,      80,      35,       25,      110,      50,      110,      80,      100,      90,        90,        90,        90,      800  }   // 立正
};


/*============================================================================*/
// Right Foot Balance Action
int Servo_Prg_34_Step = 7;
int Servo_Prg_34 [][ALLMATRIX] PROGMEM = {
  //   0    ,    1    ,    2    ,    3    ,    4    ,    5    ,    6    ,    7    ,    8    ,    9    ,    10   ,    11   ,    12   ,    13   ,    14   ,    15   ,   G12   ,  G13   ,  G14   ,  G16   ,  ms
  {   70,      80,      50,     110,     60,     135,    105,     35,      80,      85,       25,      115,      50,      110,      80,      110,      90,        90,        90,        90,      500  },
  {   70,      80,      50,     110,     60,     135,    105,     35,      80,      85,       25,      115,      50,      110,      80,      115,      90,        90,        90,        90,      300  },
  {   70,      80,      50,     110,     60,     135,    105,     35,     140,     15,      105,     100,      50,      110,      80,      120,      90,        90,        90,        90,      500  },
  {   70,      80,      50,     110,     60,     135,    105,     35,     140,     15,      105,     100,      50,      110,      80,      120,      90,       120,       90,        90,      800  },
  {   70,      80,      50,     110,     60,     135,    105,     35,      80,      85,       25,      115,      50,      110,      80,      115,      90,       120,       90,        90,      600  },
  {   70,      80,      50,     110,     60,     135,    105,     35,      80,      85,       25,      115,      50,      110,      80,      110,      90,        90,        90,        90,      500  },
  {   60,      80,      50,     110,     50,     135,    125,     80,      80,      35,       25,      110,      50,      110,      80,      100,      90,        90,        90,        90,      800  }   // 立正
};


/*============================================================================*/
// Left Foot Balance Action
int Servo_Prg_35_Step = 12;
int Servo_Prg_35 [][ALLMATRIX] PROGMEM = {
  //   0    ,    1    ,    2    ,    3    ,    4    ,    5    ,    6    ,    7    ,    8    ,    9    ,    10   ,    11   ,    12   ,    13   ,    14   ,    15   ,   G12   ,  G13   ,  G14   ,  G16   ,  ms
  {   50,      80,      50,     110,     45,     135,     50,      80,      80,     110,      25,      100,      50,      110,      80,       90,       90,        90,        90,        90,      500  },
  {   50,      80,      50,     110,     45,      85,      50,      80,      80,     110,      75,      100,      50,      110,      85,       90,       90,        90,        90,        90,      300  },
  {   45,      80,      50,     110,     60,      85,      50,      80,      80,     110,      75,      100,      50,      110,      85,       90,       90,        90,        90,        90,      500  },
  {   45,      80,      50,     110,     60,      85,      50,      80,      80,     110,      75,      100,      50,      110,      85,       90,       90,        90,        90,        90,      600  },

  {   45,      60,      50,      50,      60,      85,      50,      80,      80,     110,      75,      100,      50,      110,      85,       90,       90,        90,        90,        90,      900  },
  {   45,      60,      50,      50,      60,      85,      30,      80,      80,     130,      75,      100,      50,      110,      85,       90,       90,        60,        90,        90,      500  },
  {   45,      60,      50,      50,      60,      85,      70,      80,      80,      90,       75,      100,      50,      110,      85,       90,       90,       120,       90,        90,      500  },
  {   45,      60,      50,      50,      60,      85,      30,      80,      80,     130,      75,      100,      50,      110,      85,       90,       90,        60,        90,        90,      500  },
  {   45,      60,      50,      50,      60,      85,      70,      80,      80,      90,       75,      100,      50,      110,      85,       90,       90,       120,       90,        90,      500  },
  {   45,      60,      50,      50,      60,      85,      50,      80,      80,     110,      75,      100,      50,      110,      85,       90,       90,        90,        90,        90,      500  },
  {   45,      80,      50,     110,     60,      85,      50,      80,      80,     110,      75,      100,      50,      110,      85,       90,       90,        90,        90,        90,      800  },

  {   60,      80,      50,     110,     50,     135,    125,     80,      80,      35,       25,      110,      50,      110,      80,      100,      90,        90,        90,        90,      800  }   // 立正
};
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
void loop(void) {

  // Webpage Construction
  server.handleClient();

  // Check if there is serial message
  check_serial();

  ///////////////////////////////////////////////////////////////////////////////////////////////////////////////////////////////////////
  //Angle calculations
  ///////////////////////////////////////////////////////////////////////////////////////////////////////////////////////////////////////
  Wire.beginTransmission(gyro_address);                                     //Start communication with the gyro
  Wire.write(0x3F);                                                         //Start reading at register 3F
  Wire.endTransmission();                                                   //End the transmission
  Wire.requestFrom(gyro_address, 2);                                        //Request 2 bytes from the gyro
  accelerometer_data_raw = Wire.read()<<8|Wire.read();                      //Combine the two bytes to make one integer
  accelerometer_data_raw += acc_calibration_value;                          //Add the accelerometer calibration value
  if(accelerometer_data_raw > 8200)accelerometer_data_raw = 8200;           //Prevent division by zero by limiting the acc data to +/-8200;
  if(accelerometer_data_raw < -8200)accelerometer_data_raw = -8200;         //Prevent division by zero by limiting the acc data to +/-8200;

  angle_acc = asin((float)accelerometer_data_raw/8200.0)* 57.296;           //Calculate the current angle according to the accelerometer

  if(start == 0 && angle_acc > -0.5&& angle_acc < 0.5){                     //If the accelerometer angle is almost 0
    angle_gyro = angle_acc;                                                 //Load the accelerometer angle in the angle_gyro variable
    start = 1;                                                              //Set the start variable to start the PID controller
  }
  
  Wire.beginTransmission(gyro_address);                                     //Start communication with the gyro
  Wire.write(0x43);                                                         //Start reading at register 43
  Wire.endTransmission();                                                   //End the transmission
  Wire.requestFrom(gyro_address, 4);                                        //Request 4 bytes from the gyro
  gyro_yaw_data_raw = Wire.read()<<8|Wire.read();                           //Combine the two bytes to make one integer
  gyro_pitch_data_raw = Wire.read()<<8|Wire.read();                         //Combine the two bytes to make one integer
  
  gyro_pitch_data_raw -= gyro_pitch_calibration_value;                      //Add the gyro calibration value
  angle_gyro += gyro_pitch_data_raw * 0.000031;                             //Calculate the traveled during this loop angle and add this to the angle_gyro variable
  
  ///////////////////////////////////////////////////////////////////////////////////////////////////////////////////////////////////////
  //MPU-6050 offset compensation
  ///////////////////////////////////////////////////////////////////////////////////////////////////////////////////////////////////////
  //Not every gyro is mounted 100% level with the axis of the robot. This can be cause by misalignments during manufacturing of the breakout board. 
  //As a result the robot will not rotate at the exact same spot and start to make larger and larger circles.
  //To compensate for this behavior a VERY SMALL angle compensation is needed when the robot is rotating.
  //Try 0.0000003 or -0.0000003 first to see if there is any improvement.

  gyro_yaw_data_raw -= gyro_yaw_calibration_value;                          //Add the gyro calibration value
  //Uncomment the following line to make the compensation active
  //angle_gyro -= gyro_yaw_data_raw * 0.0000003;                            //Compensate the gyro offset when the robot is rotating

  angle_gyro = angle_gyro * 0.9996 + angle_acc * 0.0004;                    //Correct the drift of the gyro angle with the accelerometer angle

  display.clearDisplay();
  display.setCursor(0, 32);
  display.println("P= " + String(gyro_pitch_data_raw));
  display.println("Y= " + String(gyro_yaw_data_raw));
  //display.display();




  // Basic Actions
  if (Servo_PROGRAM >= 1 && Input_Voltage_Low == 0 )
  {

    //Serial.print("Servo_PROGRAM = ");
    //Serial.println(Servo_PROGRAM);

    OLED_Display_Index = OLED_Display_Index + 8;
    if (OLED_Display_Index > 56) {
      OLED_Display_Index = 0;
      display.clearDisplay();
    }
    display.clearDisplay();
    display.setCursor(0, 24);
    display.print("Servo_PROGRAM = ");
    display.println(Servo_PROGRAM);
    display.display();

    switch (Servo_PROGRAM)
    {
      case 1:  // forward
        Servo_PROGRAM_Run(Servo_Prg_1, Servo_Prg_1_Step);
        Servo_PROGRAM_Center();
        break;
      case 2:  // backward
        Servo_PROGRAM_Run(Servo_Prg_2, Servo_Prg_2_Step);
        Servo_PROGRAM_Center();
        break;
      case 3:  // Turn Left
        Servo_PROGRAM_Run(Servo_Prg_3, Servo_Prg_3_Step);
        Servo_PROGRAM_Center();
        break;
      case 4:  // Turn Right
        Servo_PROGRAM_Run(Servo_Prg_4, Servo_Prg_4_Step);
        Servo_PROGRAM_Center();
        break;
      case 5:  // Move left
        Servo_PROGRAM_Run(Servo_Prg_5, Servo_Prg_5_Step);
        Servo_PROGRAM_Center();
        break;
      case 6:  // Move Rigth
        Servo_PROGRAM_Run(Servo_Prg_6, Servo_Prg_6_Step);
        Servo_PROGRAM_Center();
        break;
      case 7:  // Left Kick
        Servo_PROGRAM_Run(Servo_Prg_7, Servo_Prg_7_Step);
        Servo_PROGRAM_Center();
        break;
      case 8:  // Right Kick
        Servo_PROGRAM_Run(Servo_Prg_8, Servo_Prg_8_Step);
        Servo_PROGRAM_Center();
        break;
      case 9:  // Slide (Skate) Forward
        Servo_PROGRAM_Run(Servo_Prg_9, Servo_Prg_9_Step);
        Servo_PROGRAM_Center();
        break;
      case 10: // Slide (skate) Back
        Servo_PROGRAM_Run(Servo_Prg_10, Servo_Prg_10_Step);
        Servo_PROGRAM_Center();
        break;
      case 11: // Facing Upwards
        Servo_PROGRAM_Run(Servo_Prg_11, Servo_Prg_11_Step);
        Servo_PROGRAM_Center();
        break;
      case 12: // Stand upside down
        Servo_PROGRAM_Run(Servo_Prg_12, Servo_Prg_12_Step);
        Servo_PROGRAM_Run(Servo_Prg_39_3, Servo_Prg_39_3_Step);
        Servo_PROGRAM_Center();
        break;
      case 99: // Standby
        Servo_PROGRAM_Center();
        delay(300);
        break;
      case 100:  // Davinci Posture
        Servo_PROGRAM_Zero();
        delay(300);
        break;
    }
    Servo_PROGRAM = 0;
  }


  // Action Set
  if (Servo_PROGRAM_Stack >= 1 && Input_Voltage_Low == 0 )
  {

    //Serial.print("Servo_PRGRAM_Stack = ");
    //Serial.println(Servo_PROGRAM_Stack);
    
    display.setCursor(0, 24);
    display.print("Servo_PRG_Stack = ");
    display.println(Servo_PROGRAM_Stack);
    display.display();
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

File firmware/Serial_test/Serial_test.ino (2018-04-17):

#include <SPI.h>
#include <Wire.h>
#include <Servo.h>
#include <Adafruit_GFX.h>
#include <Adafruit_SSD1306.h>


//  I2C Address 0x3C
#define OLED_RESET LED_BUILTIN
Adafruit_SSD1306 display(-1);

// Serial port input
byte byteRead;
long num1, num2, num3;
long number1, number2, number3;
boolean mySwitch2=false;
boolean mySwitch3=false;


/*============================================================================*/
void check_serial() {

  while (Serial.available()) {
    //Read the most recent byte
    byteRead = Serial.read();

    //listen for numbers between 0-9
    if(byteRead>47 && byteRead<58){
       //number found
      
       /* If mySwitch is true, then populate the num1 variable
          otherwise populate the num2 variable*/
       if(!mySwitch2 && !mySwitch3){
         num1=byteRead-48;
       }
       if(mySwitch2 && !mySwitch3){
         num2=(num2*10)+(byteRead-48);
       }
       if(mySwitch2 && mySwitch3){
         num3=(num3*10)+(byteRead-48);
       }
    }
    
    /*Listen for an equal sign (byte code 61) 
      to calculate the answer and send it back to the
      serial monitor screen*/
    if(byteRead==61){
      number1 = num1;
      number2 = num2;
      number3 = num3;
      
      
      Serial.print(num1);
      Serial.print(",");
      Serial.print(num2);
      Serial.print(",");
      Serial.print(num3);
      Serial.println("=");

      //display.setCursor(0, 0);
      //display.print("Ser= ");
      //display.print(num1);
      //display.print(",");
      //display.print(num2);
      //display.print("=");
      //display.display();
      
      /* Reset the variables for the next round */
      num1=0;
      num2=0;
      num3=0;
      mySwitch2=false;
      mySwitch3=false;
      
    /* Listen for a comma (byte code 44). This is
       used as a delimiter to help define num1 from num2 */  
    }else if (byteRead==44 && !mySwitch2){
      mySwitch2=true;
    }else if (byteRead==44 && mySwitch2 && !mySwitch3){
      mySwitch3=true;
    }
  }
}






/*============================================================================*/
void setup(void) {

  Serial.begin(9600);
  Serial.println("Serial Started");

  num1=0;
  num2=0;
  num3=0;


  // Initialize I2C
  Wire.begin(4, 5);
  Wire.setClock(400000);
  
  // Initialize I2C OLED
  display.begin(SSD1306_SWITCHCAPVCC, 0x3C);

  // Clear the buffer.
  display.clearDisplay();
  display.display();

  display.setTextSize(1);
  display.setTextColor(WHITE);
  display.setCursor(0, 0);
  //display.println("MiniPlan V6 Start !");
  display.display();

}

/*============================================================================*/
void loop(void) {

  // Check if there is serial message
  check_serial();


  //Serial.print("Started loop ");
  //Serial.println(Servo_PROGRAM);

  display.clearDisplay();
  display.setCursor(0, 0);
  display.print("num1 = ");
  display.println(number1);

  display.setCursor(0, 8);
  display.print("num2 = ");
  display.println(number2);

  display.setCursor(0, 16);
  display.print("num3 = ");
  display.println(number3);
  display.display();



}

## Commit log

2017-10-26 splitter Openscad file and Generated images and stls using batch file
    [Citro.scad, Citro5_40.scad, Citro5_40.stl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]
2017-10-30 Fixed Openscad files and started Asembly Instructions Animation
    [Assembly_Steps.scad, Assembly_Steps.stl, Citro.scad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]
2018-04-06 Updated openscad files and added arduino sketch for ESP8266
    [Citro.scad, Citro6_11.scad, Citro6_12A.scad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]
2018-08-11 updates to blender model
    [Citro6_52.scad, Citro6_52a.stl, Citro6_RightLeg.blend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]
2018-08-12 added eyes - citro6_54.stl and worked blender model
    [Citro6_50.scad, Citro6_54.scad, Citro6_54.stl]
2018-08-16 added rig for rightleg
    [Citro6_RightLeg.blend, Config.scad, Servo_wire.scad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]
2018-08-20 added rigging to right leg
    [Citro6_RightLeg.blend]
2018-08-30 added RightLegAssemblyAnimation.blend
    [RightLegAssemblyAnimation.blend]
2018-09-07 modeled wire for servo
    [wire.blend, wire2.blend, wire3.blend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]
